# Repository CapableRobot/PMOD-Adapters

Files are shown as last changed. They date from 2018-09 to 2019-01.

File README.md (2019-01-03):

# PMOD Adapters

Designed by [Capable Robot Components](http://capablerobot.com).  Follow us on [Twitter](http://twitter.com/capablerobot) for product announcements and updates.

---

This repository contains schematics, layout, and bill of materials for various PMOD adapters and interfaces.  This currently includes:

* 2019-01-30 : [CRBFH0 - LED Debug](boards/LED-Debug)
* 2019-01-30 : [CR6QEG - PMOD Debug](boards/Debug)
* 2018-09-13 : [CR7CSZ - BeagleWire to PMOD](boards/BeagleWire) 
* 2018-09-13 : [CRRYEK - BeagleWire to Debug PMOD](boards/BeagleWire-Debug)

Additional designed will be added to this repository over time.  

| **Type** | **License** |
| --- | --- |
| Hardware | Copyright Capable Robot Components 2018 <br><br>This documentation describes Open Hardware and is licensed under the [CERN OHL v1.2 or later](https://www.ohwr.org/licenses/cern-ohl/license_versions/v1.2). <br/><br/> You may redistribute and modify this documentation under the terms of the CERN OHL v.1.2.  This documentation is distributed WITHOUT ANY EXPRESS OR IMPLIED WARRANTY, INCLUDING OF MERCHANTABILITY, SATISFACTORY QUALITY AND FITNESS FOR A PARTICULAR PURPOSE. Please see the CERN OHL v.1.2 for applicable conditions |
| Software | [MIT License](LICENSE.txt) |

More detailed information about the CERN License is available in the [license](license) folder and on the [CERN website](https://www.ohwr.org/projects/cernohl/wiki).

---

### [CRBFH0] LED Debug

| Top Render | Bottom Render |
| :---: | :---: |
| **Top Rendering** | **Bottom Rendering** |

This PCB allows a single PMOD to control 64 LEDs via a 4:16 address decoder and 4 mask control signals.  It was originally designed by H.Poetzl as part of the [Apertus project](https://www.apertus.org/pmod-debug).  Changes made to this version are:

- Changed 0402 resistors to 0603 packages.
- Changed the N channel MOSFETs from SC75 to SOT23 packages. 
- PCB layout changes to accommodate the larger components.

No schematic changes were made, meaning the PMOD interface is identical.

This board can be ordered at [OSH Park](https://oshpark.com/shared_projects/n7GHOesv) and costs $6.75 for a set of 3.



---

### [CR6QEG] PMOD Debug

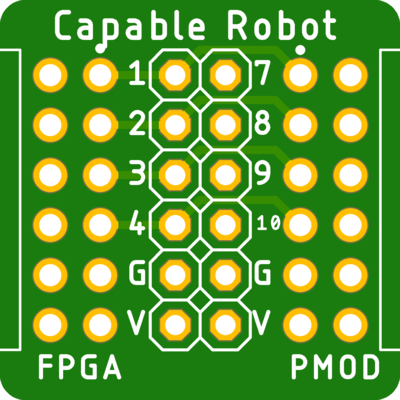
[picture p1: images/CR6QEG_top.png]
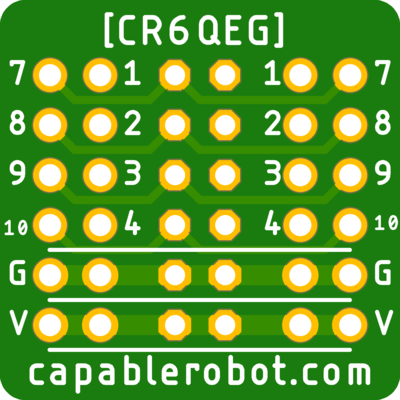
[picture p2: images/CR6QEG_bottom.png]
Bottom Render
|  |  |
| :---: | :---: |
| **Top Rendering** | **Bottom Rendering** |

This PCB adapts allows for probing of signals between an FPGA development board an a PMOD peripheral.  

A 2x6 right angle male header should be installed in the `FPGA` header and a 2x6 right angle female header should be installed into the `PMOD` header.

This board can be ordered at [OSH Park](https://oshpark.com/shared_projects/YEDBhzJa) and costs $3.20 for a set of 3.



---

### [CR7CSZ] BeagleWire to PMOD

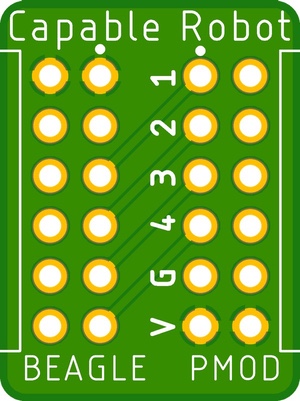
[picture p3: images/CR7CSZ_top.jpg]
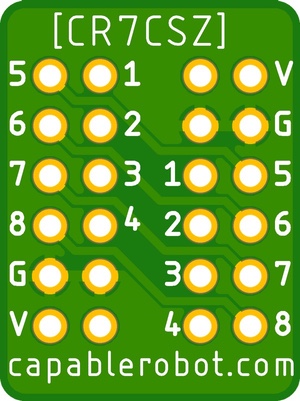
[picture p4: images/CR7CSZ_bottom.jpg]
Bottom Render
|  |  |
| :---: | :---: |
| **Top Rendering** | **Bottom Rendering** |

This PCB adapts standard PMOD peripherals to the BeagleWire PMOD connectors.  

The BeagleWire has a reversed pinout wherein the Power and Ground are on the right side of the connector (as you face a female PMOD on the BeagleWire) while all other PMOD hosts have the Power and Ground on the left side of the connector.

A 2x6 right angle male header should be installed in the `BEAGLE` header and a 2x6 right angle female header should be installed into the `PMOD` header.

This board can be ordered at [OSH Park](https://oshpark.com/shared_projects/sm0OcuML) and costs $2.40 for a set of 3.



---

### [CRRYEK] BeagleWire to Debug PMOD

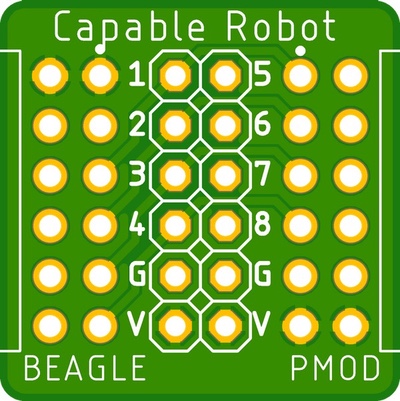
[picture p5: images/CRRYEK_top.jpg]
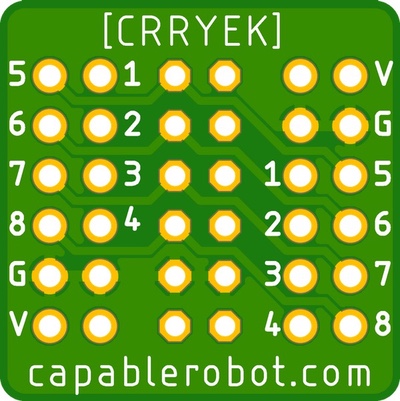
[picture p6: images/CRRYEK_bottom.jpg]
Bottom Render
|  |  |
| :---: | :---: |
| **Top Rendering** | **Bottom Rendering** |

This PCB adapts standard PMOD peripherals to the BeagleWire PMOD connectors.  It is similar to the CR7CSZ version but adds an additional 2x6 header (standard PMOD pinout) to aid in probing and debugging signals between the BeagleWire and the PMOD peripheral.

A 2x6 right angle male header should be installed in the `BEAGLE` header and a 2x6 right angle female header should be installed into the `PMOD` header.

This board can be ordered at [OSH Park](https://oshpark.com/shared_projects/SsbzeQ1o) and costs $3.20 for a set of 3.



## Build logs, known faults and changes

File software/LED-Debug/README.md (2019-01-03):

## LED Debug Migen Code

The `led-pmod.py` file here is a small driver for the LED Debug PMOD board.

| Top Render | Bottom Render |
| :---: | :---: |
| **Top Rendering** | **Bottom Rendering** |

This PCB allows a single PMOD to control 64 LEDs via a 4:16 address decoder and 4 mask control signals.  It was originally designed by H.Poetzl as part of the [Apertus project](https://www.apertus.org/pmod-debug) and they provide example [VHDL code](https://github.com/apertus-open-source-cinema/alpha-software/blob/master/axi3_hdmi/pmod_debug.vhd) showing how to address the LEDs.

Source files for this LED Debug PCB are available in this repository, see [https://github.com/CapableRobot/PMOD-Adapters](https://github.com/CapableRobot/PMOD-Adapters).

The python-based Migen code to address the LEDs is very simple

```python
class LedPmod(Module):
    def __init__(self, platform, value):
        
        clock = Signal()
        clock_strobe  = Signal()

        addr = Signal(4)
        mask = Signal(4)

        if platform == 'sim':
            div = 1
        else:
            div = 8

            for i in range(4):
                ledpmod_mask = platform.request("ledpmod_mask")
                ledpmod_addr = platform.request("ledpmod_addr")

                self.comb += ledpmod_mask.eq(mask.part(i,1))
                self.comb += ledpmod_addr.eq(addr.part(i,1))

        self.submodules.clk_div = ClockDiv(div, clock, clock_strobe)

        self.comb += mask.eq(Cat(
                        ~value.part(addr     ,1),
                        ~value.part(addr + 16,1),
                        ~value.part(addr + 32,1),
                        ~value.part(addr + 48,1)
                    ))

        self.sync += If(clock_strobe,
                            addr.eq(addr + 1),
                        )
```

This shows a few unique features to Migen (in comparison to Verilog or VHDL):

- The appropriate pins are requested from the passed-in platform object, instead of explicitly passed into the module.
- Signals are automatically initialized to 0, so no reset logic or signal is needed.
- Generated logic is easy to change at build time.  Here, the clock divider changes when the package is simulated.

Also included in the code here are two examples of using this 'driver'.

#### Chasing

```python
class LedPmodChaser(Module):
    
    def __init__(self, platform, maxperiod):
        NUM_LEDS = 64

        value = Signal(NUM_LEDS,reset=1)
        index = Signal(max=NUM_LEDS)

        counter = Signal(max=maxperiod+1)
        period = Signal(max=maxperiod+1)

        # Used to trigger the bit flip via the index.
        # without this signal, the active bit/LED will change
        # on every system clock (making it dimmer).
        strobe = Signal()

        self.submodules.leds = LedPmod(platform, value)
        
        self.comb += period.eq(maxperiod)
        self.sync += If(counter == 0,
                            index.eq(index + 1),
                            strobe.eq(1),
                            counter.eq(period),
                        ).Else(
                            counter.eq(counter - 1),
                        )

        for i in range(NUM_LEDS): 
            self.sync += If(index == i, If(strobe,
                            strobe.eq(0),
                            value[i].eq(~value[i]),
                        ))
```

This code starts at zero, every `maxperiod` ticks lights the next LED.  Once all leds are lit, every `maxperiod` ticks the LED which has been on the longest is turned off.

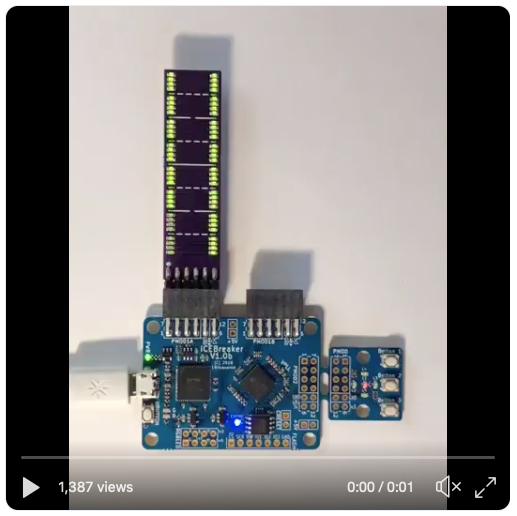
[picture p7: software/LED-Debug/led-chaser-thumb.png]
(https://twitter.com/osterwood/status/1080574349827026951)
|  |
| :-------------: |
| ICE Breaker running Chasing Demo  |

| Simulation of chasing |
| :-------------: |
| Simulation of chasing |

#### Counting

```python
class LedPmodCounter(Module):
    def __init__(self, platform, maxperiod):
        value = Signal(64)

        counter = Signal(max=maxperiod+1)
        period = Signal(max=maxperiod+1)

        self.submodules.leds = LedPmod(platform, value)
        
        self.comb += period.eq(maxperiod)
        self.sync += If(counter == 0,
                            value.eq(value + 1),
                            counter.eq(period),
                        ).Else(
                            counter.eq(counter - 1),
                        )
```

This code starts at zero, every `maxperiod` ticks increases the displayed value by 1.

| Simulation of counting |
| :-------------: |
| Simulation of counting |

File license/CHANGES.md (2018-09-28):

Here we are compiling a community changelog.

If you come up with a modification of our designs, please share it
with the community, log your changes below, and upload the files to
our GitHub repository.

# Change Format

**Your name**
*Date*
Description of modification

# Change Log

* **Chris Osterwood** *2018-09-13* Initial release of [CR7CSZ - BeagleWire to PMOD](boards/BeagleWire) and [CRRYEK - BeagleWire to Debug PMOD](boards/BeagleWire-Debug)

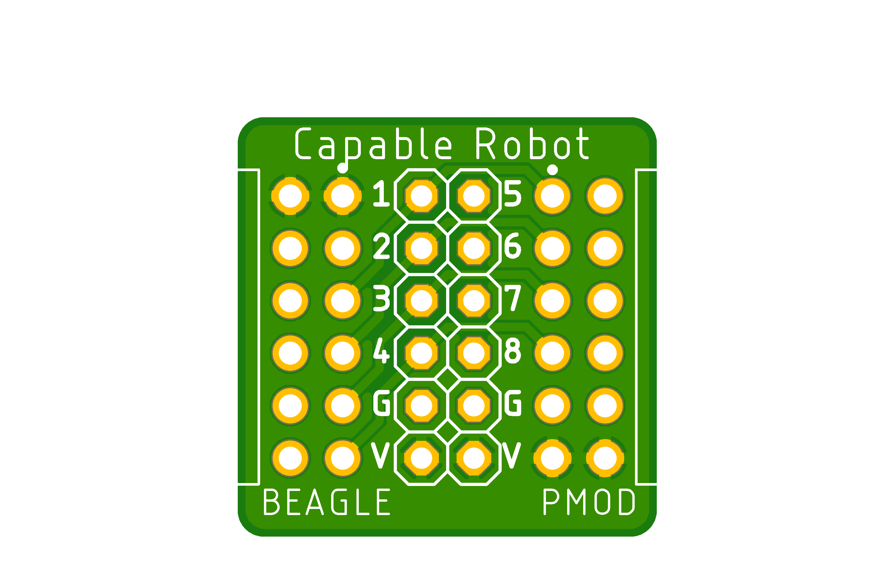
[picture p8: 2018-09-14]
boards/BeagleWire-Debug/top.png

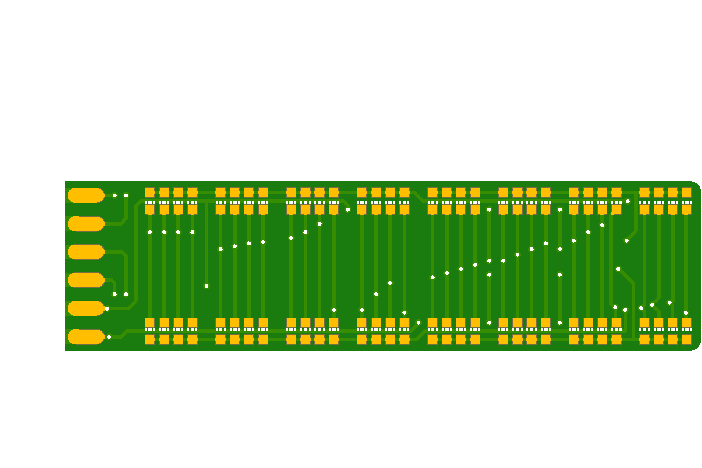
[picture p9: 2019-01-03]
boards/LED-Debug/top.png

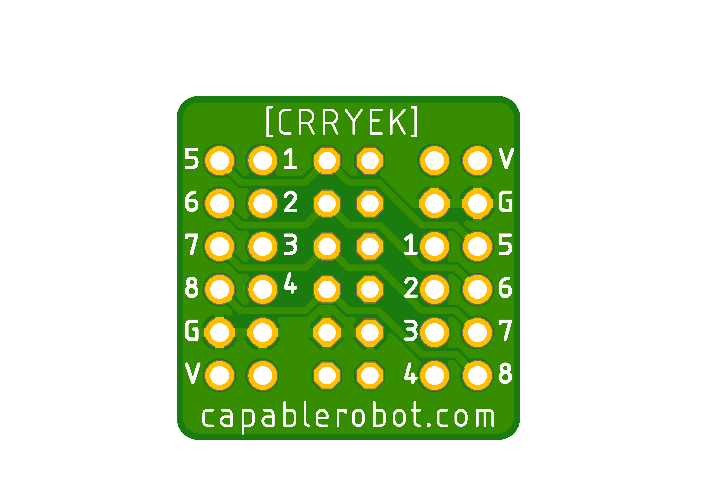
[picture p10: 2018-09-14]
boards/BeagleWire-Debug/bottom.png

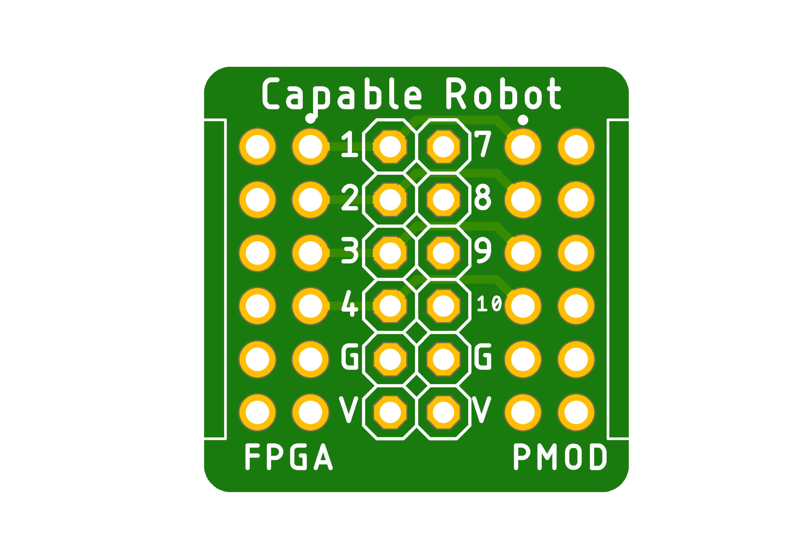
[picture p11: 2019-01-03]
boards/Debug/top.png

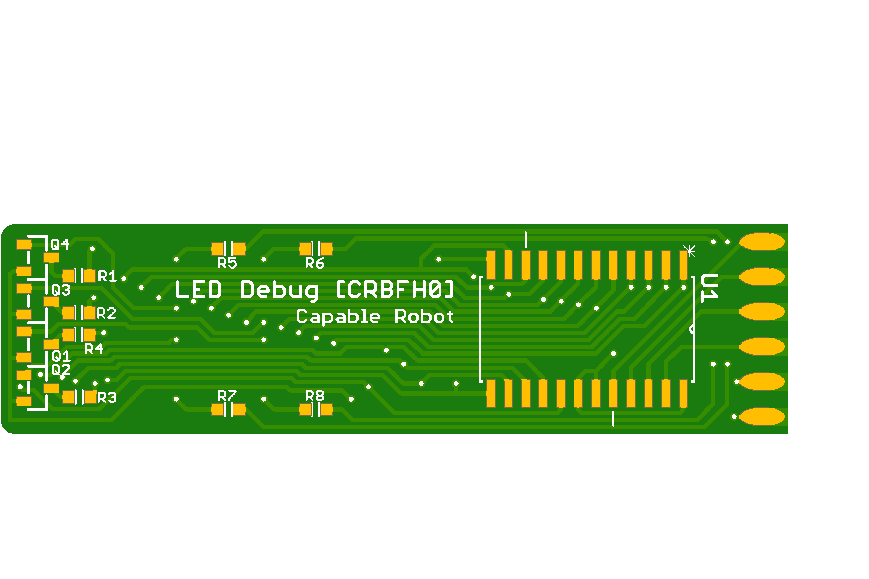
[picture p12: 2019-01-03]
boards/LED-Debug/bottom.png

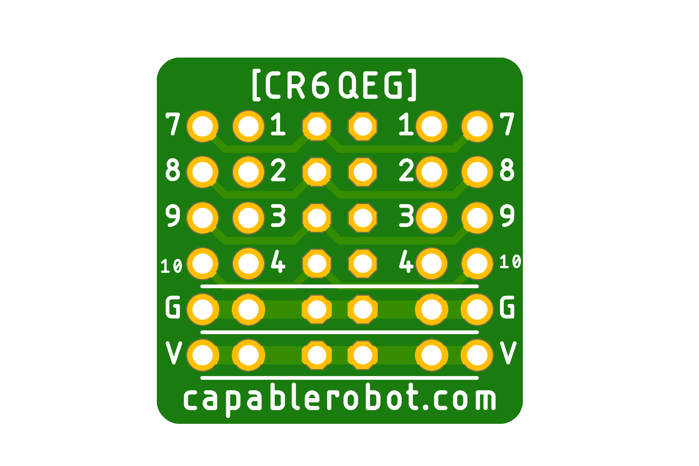
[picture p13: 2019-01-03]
boards/Debug/bottom.png

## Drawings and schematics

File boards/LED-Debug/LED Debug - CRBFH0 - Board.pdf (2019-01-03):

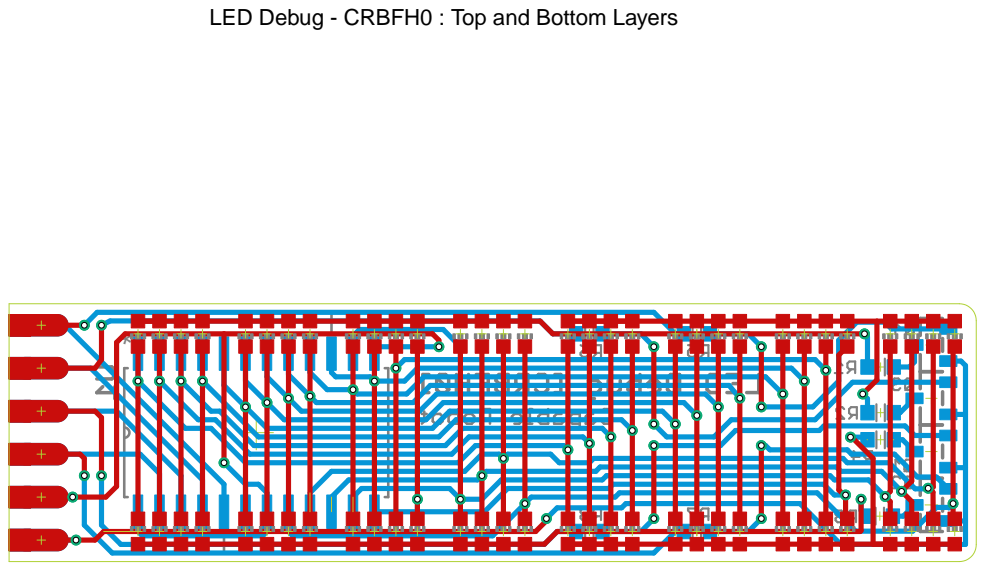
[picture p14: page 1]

LED Debug - CRBFH0 : Top and Bottom Layers

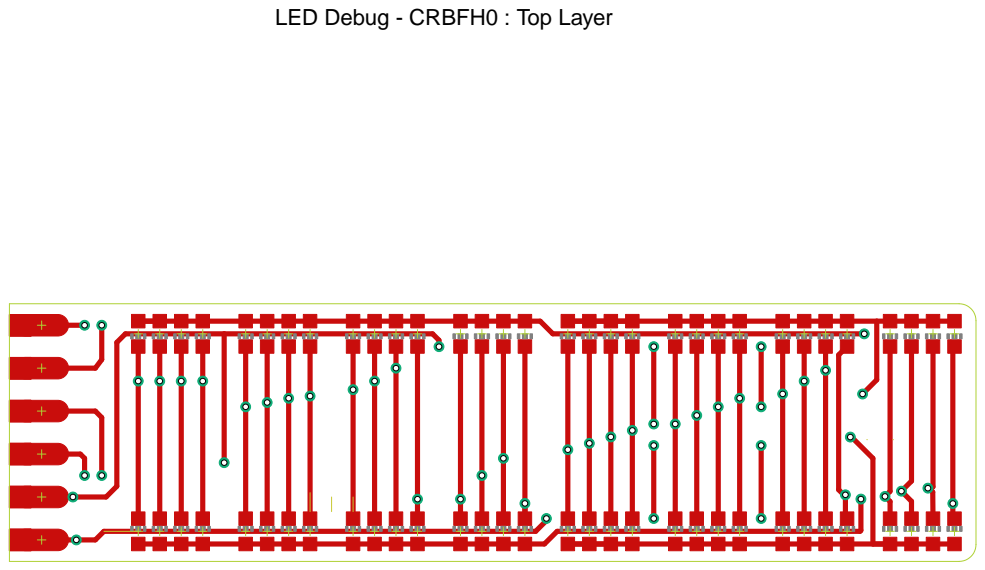
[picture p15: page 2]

LED Debug - CRBFH0 : Top Layer

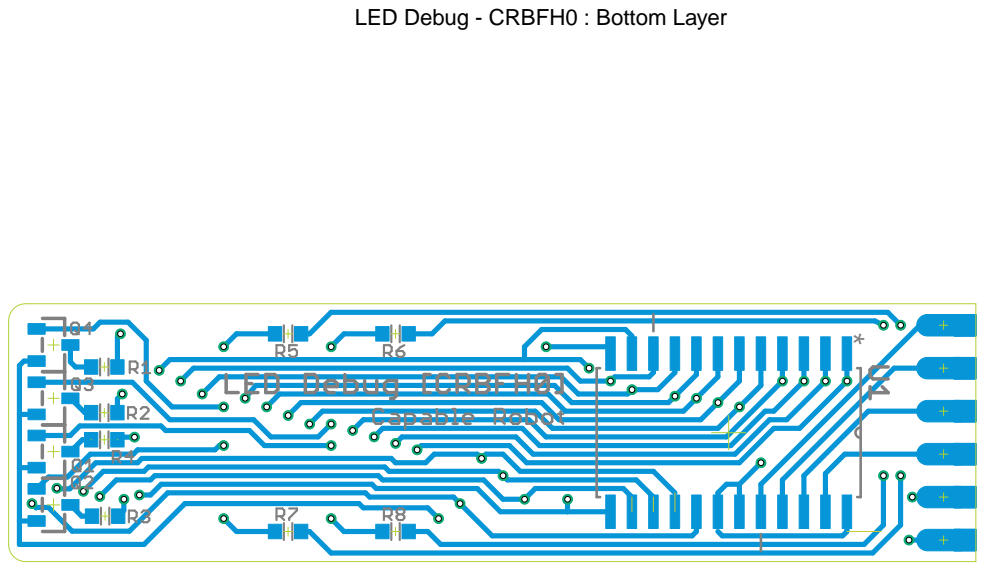
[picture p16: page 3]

LED Debug - CRBFH0 : Bottom Layer

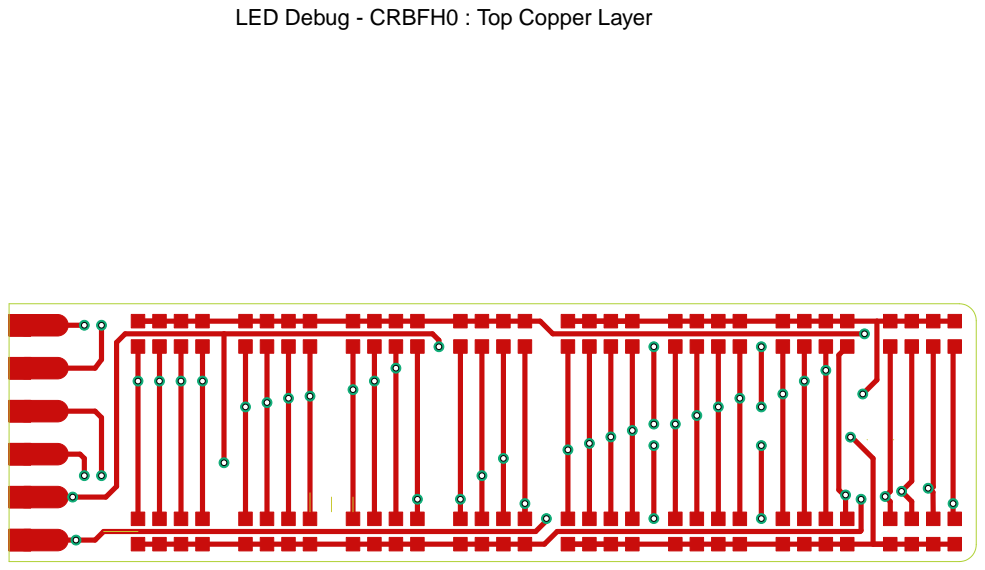
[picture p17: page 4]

LED Debug - CRBFH0 : Top Copper Layer

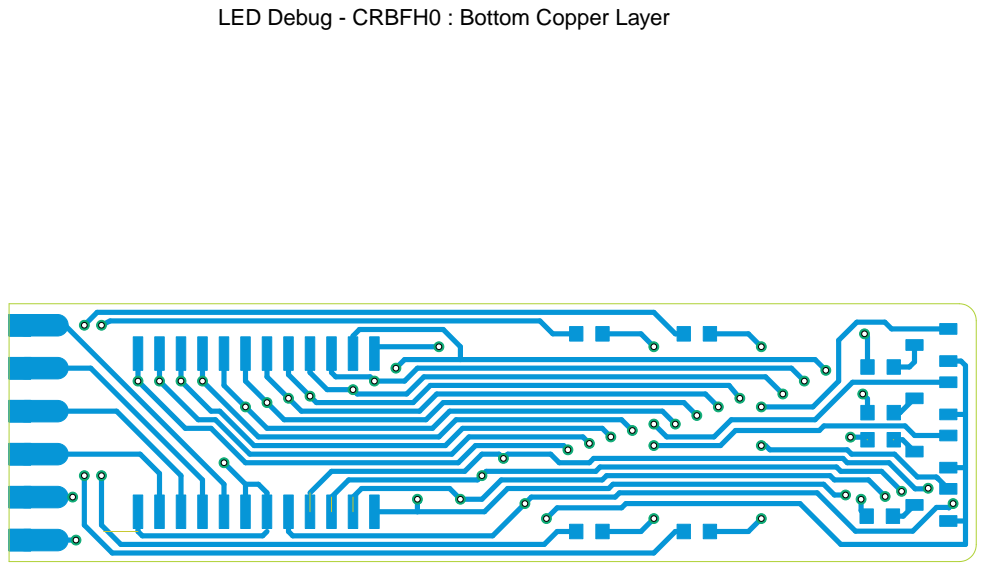
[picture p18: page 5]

LED Debug - CRBFH0 : Bottom Copper Layer

LED Debug - CRBFH0 : Top Paste Layer with Silkscreen

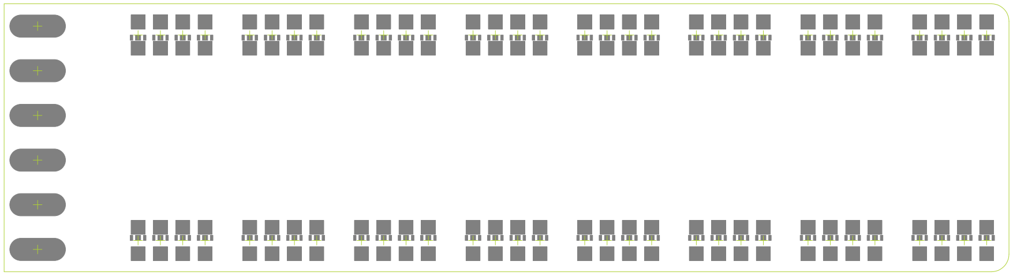
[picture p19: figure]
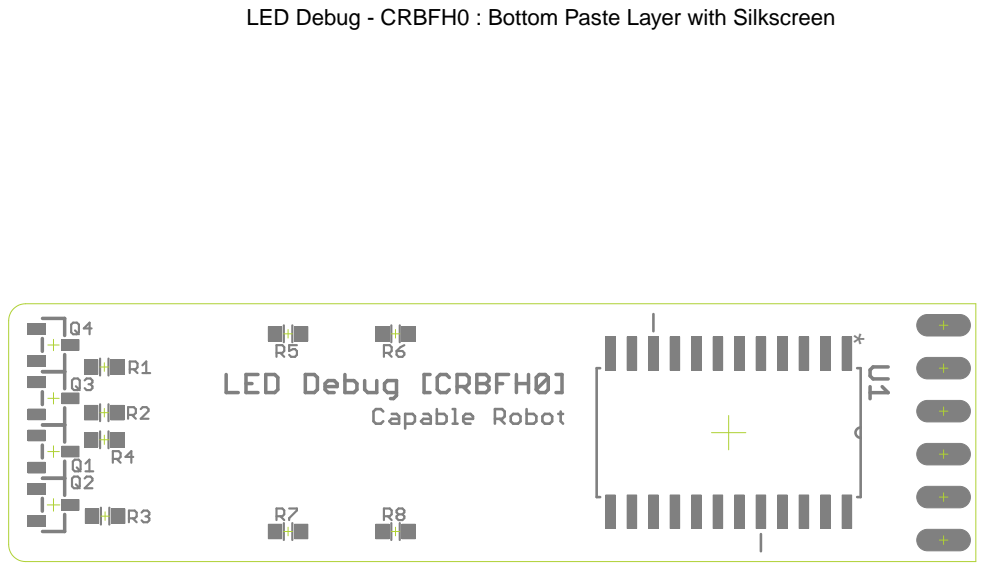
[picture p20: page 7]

LED Debug - CRBFH0 : Bottom Paste Layer with Silkscreen

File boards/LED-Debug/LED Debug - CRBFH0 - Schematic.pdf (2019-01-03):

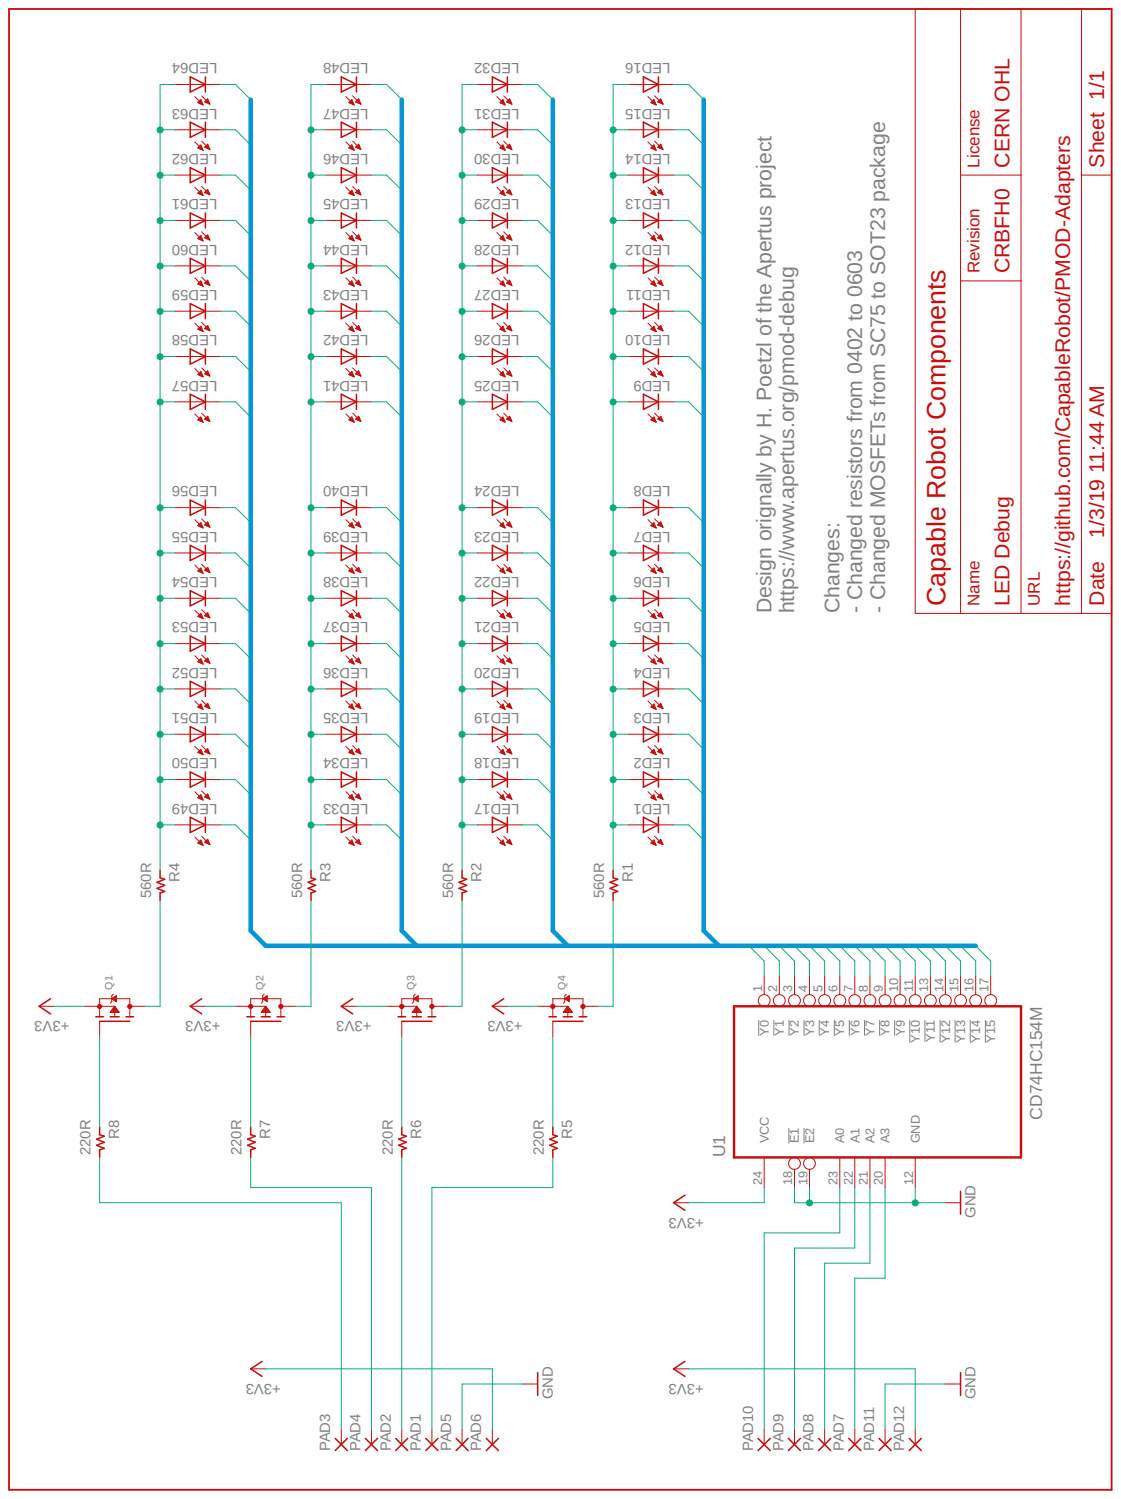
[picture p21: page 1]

Design orignally by H. Poetzl of the Apertus project https:/ w .apertus.org/pmod-debug Changes: - Changed resistors from 0402 to 0603

https:/ github.com/CapableRobot/PM

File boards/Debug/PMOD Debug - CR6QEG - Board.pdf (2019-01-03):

# Capable Robot

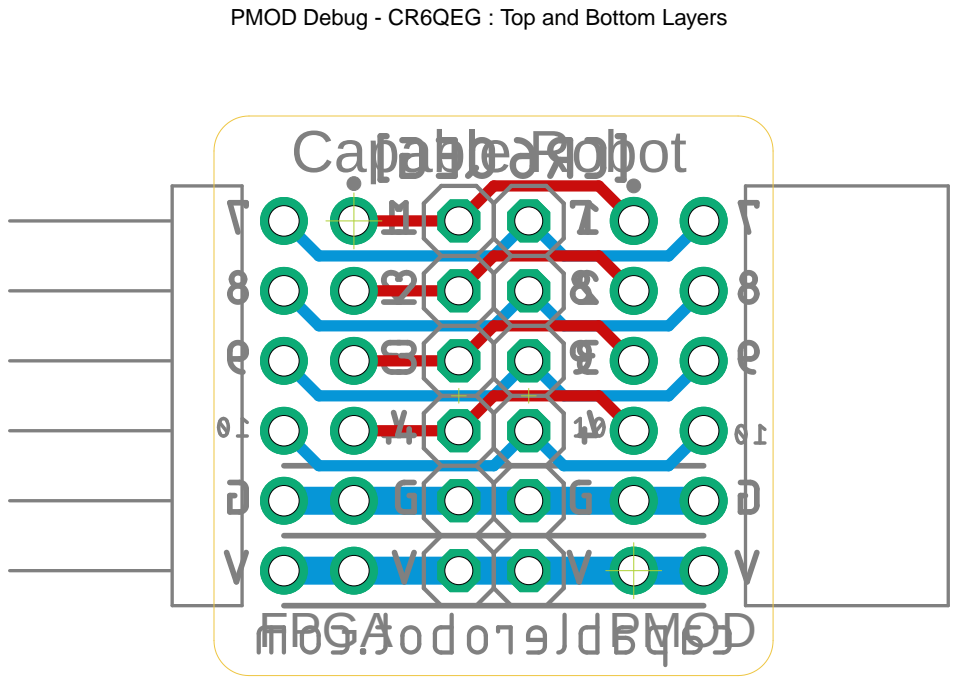
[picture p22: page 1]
FPGA; PMOD

PMOD Debug - CR6QEG : Top and Bottom Layers

# Capable Robot

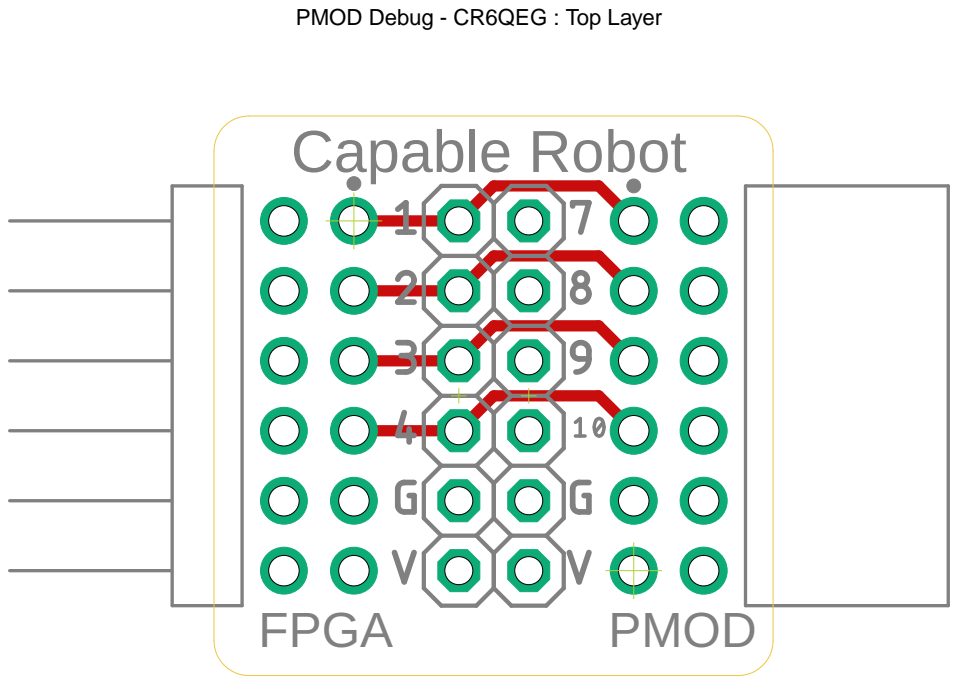
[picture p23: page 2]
FPGA; PMOD

PMOD Debug - CR6QEG : Top Layer

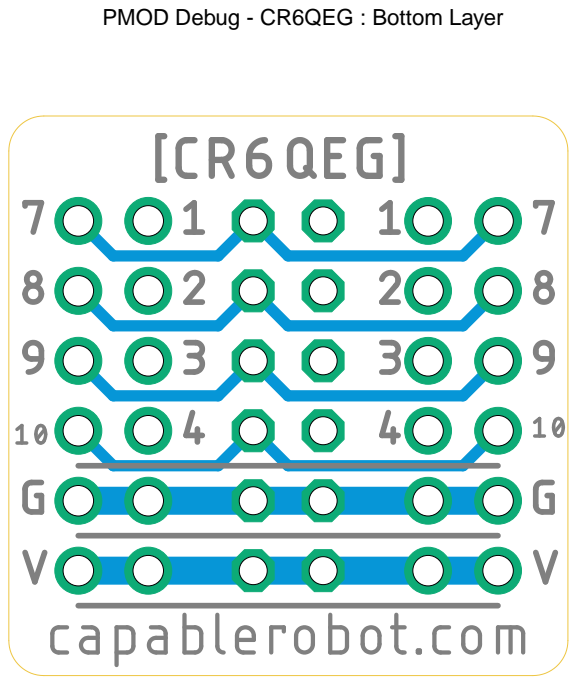
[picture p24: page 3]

PMOD Debug - CR6QEG : Bottom Layer

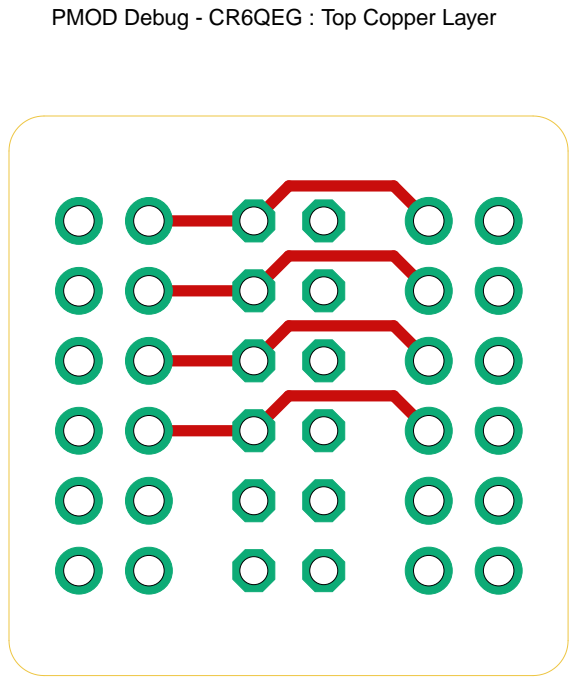
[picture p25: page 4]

PMOD Debug - CR6QEG : Top Copper Layer


PMOD Debug - CR6QEG : Bottom Copper Layer

# Capable Robot

FPGA; PMOD

PMOD Debug - CR6QEG : Top Paste Layer with Silkscreen


PMOD Debug - CR6QEG : Bottom Paste Layer with Silkscreen

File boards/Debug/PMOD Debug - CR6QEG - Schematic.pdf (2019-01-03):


PMOD PMOD GND GND GND GND GND PMOD FPGA GND IO1 1 IO2 2 IO3 3 IO4 4 GND 5 3V3 6 GND 11 3V3 12 IO8 10 IO7 9 IO6 8 IO5 7 +3V3 +3V3 +3V3 +3V3 123456 JP1 123456 JP2 +3V3 IO1 1 IO2 2 IO3 3 IO4 4 GND 5 3V3 6 GND 11 3V3 12 IO8 10 IO7 9 IO6 8 IO5 7 +3V3 IO4IO4 IO4 IO3IO3 IO3 IO2IO2 IO2 IO1IO1 IO1 IO7 IO7 IO7 IO8 IO8 IO8 IO9 IO9 IO9 IO10 IO10 IO10Date Sheet Revision Name Capable Robot Components URL License 1/3/19 10:28 AM 1/1 PMOD Debug CR6QEG https:/ github.com/CapableRobot/PMOD-Adapters CERN OHL v1.2

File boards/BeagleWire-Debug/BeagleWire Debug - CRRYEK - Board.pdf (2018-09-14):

# Ca]paKbEleYRRRobC[ot

BEAGLE; PMOD

PMOD to BeagleWire Debug - CRRYEK : Top and Bottom Layers

# Capable Robot

BEAGLE; PMOD

PMOD to BeagleWire Debug - CRRYEK : Top Layer

# [CRRYEK]


PMOD to BeagleWire Debug - CRRYEK : Bottom Layer


PMOD to BeagleWire Debug - CRRYEK : Top Copper Layer


PMOD to BeagleWire Debug - CRRYEK : Bottom Copper Layer

# Capable Robot

BEAGLE; PMOD

PMOD to BeagleWire Debug - CRRYEK : Top Paste Layer with Silkscreen

# [CRRYEK]


PMOD to BeagleWire Debug - CRRYEK : Bottom Paste Layer with Silkscreen

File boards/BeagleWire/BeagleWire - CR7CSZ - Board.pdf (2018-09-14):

# Ca]paZbSleC7RRoCb[ot

BEAGLE; PMOD

PMOD to BeagleWire - CR7CSZ : Top and Bottom Layers

# Capable Robot

BEAGLE PMOD

PMOD to BeagleWire - CR7CSZ : Top Layer

# [CR7CSZ]


PMOD to BeagleWire - CR7CSZ : Bottom Layer


PMOD to BeagleWire - CR7CSZ : Top Copper Layer


PMOD to BeagleWire - CR7CSZ : Bottom Copper Layer

PMOD to BeagleWire - CR7CSZ : Top Paste Layer with Silkscreen

Capable Robot; BEAGLE PMOD

# [CR7CSZ]


PMOD to BeagleWire - CR7CSZ : Bottom Paste Layer with Silkscreen

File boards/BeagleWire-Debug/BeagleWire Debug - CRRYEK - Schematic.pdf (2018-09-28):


URL
https://github.com/CapableRobot/PMOD-Adapters

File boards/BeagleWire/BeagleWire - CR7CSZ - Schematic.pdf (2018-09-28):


URL
https://github.com/CapableRobot/PMOD-Adapters

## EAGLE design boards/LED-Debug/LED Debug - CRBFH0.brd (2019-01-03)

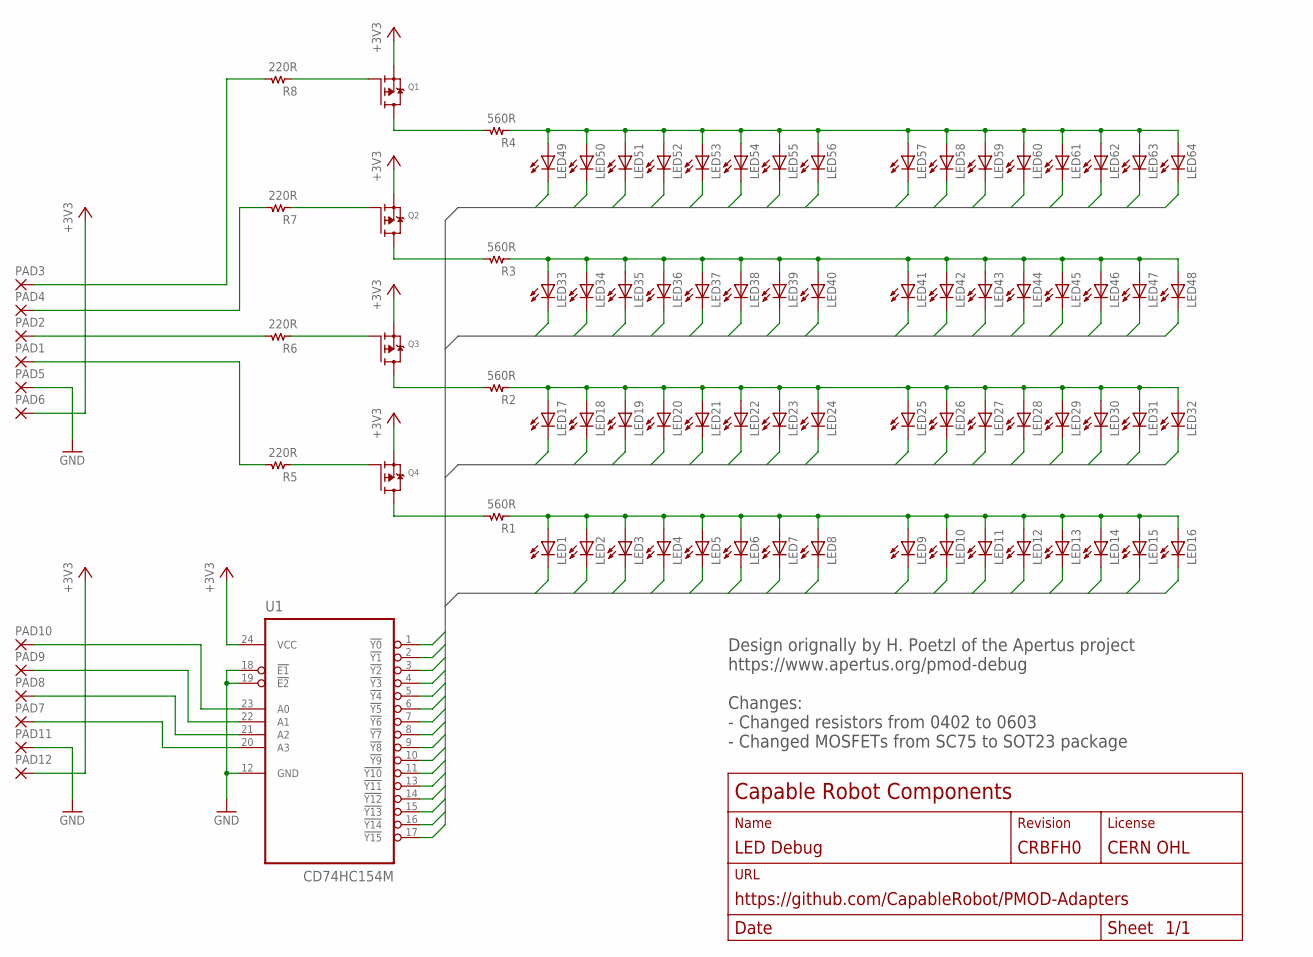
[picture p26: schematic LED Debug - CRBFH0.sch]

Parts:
LED1, LED2, LED3, LED4, LED5, LED6, LED7, LED8, LED9, LED10, LED11, LED12, LED13, LED14, LED15, LED16, LED17, LED18, LED19, LED20, LED21, LED22, LED23, LED24, LED25, LED26, LED27, LED28, LED29, LED30, LED31, LED32, LED33, LED34, LED35, LED36, LED37, LED38, LED39, LED40, LED41, LED42, LED43, LED44, LED45, LED46, LED47, LED48, LED49, LED50, LED51, LED52, LED53, LED54, LED55, LED56, LED57, LED58, LED59, LED60, LED61, LED62, LED63, LED64: LEDCHIP-LED0603; CHIP-LED0603
PAD1, PAD2, PAD3, PAD4, PAD5, PAD6, PAD7, PAD8, PAD9, PAD10, PAD11, PAD12: SMD2HR; SMD1.27-3.175HR
Q1, Q2, Q3, Q4: MOSFET-P; SOT23-R
R1, R2, R3, R4: 560R; 0603
R5, R6, R7, R8: 220R; 0603
U1: CD74HC154M; SOIC127P1030X265-24N

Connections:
+3V3: PAD6.1, PAD12.1, Q1.2 (S), Q2.2 (S), Q3.2 (S), Q4.2 (S), U1.24 (VCC)
C0: LED1.C, LED17.C, LED33.C, LED49.C, U1.1 (!Y0)
C1: LED2.C, LED18.C, LED34.C, LED50.C, U1.2 (!Y1)
C2: LED3.C, LED19.C, LED35.C, LED51.C, U1.3 (!Y2)
C3: LED4.C, LED20.C, LED36.C, LED52.C, U1.4 (!Y3)
C4: LED5.C, LED21.C, LED37.C, LED53.C, U1.5 (!Y4)
C5: LED6.C, LED22.C, LED38.C, LED54.C, U1.6 (!Y5)
C6: LED7.C, LED23.C, LED39.C, LED55.C, U1.7 (!Y6)
C7: LED8.C, LED24.C, LED40.C, LED56.C, U1.8 (!Y7)
C8: LED9.C, LED25.C, LED41.C, LED57.C, U1.9 (!Y8)
C9: LED10.C, LED26.C, LED42.C, LED58.C, U1.10 (!Y9)
C10: LED11.C, LED27.C, LED43.C, LED59.C, U1.11 (!Y10)
C11: LED12.C, LED28.C, LED44.C, LED60.C, U1.13 (!Y11)
C12: LED13.C, LED29.C, LED45.C, LED61.C, U1.14 (!Y12)
C13: LED14.C, LED30.C, LED46.C, LED62.C, U1.15 (!Y13)
C14: LED15.C, LED31.C, LED47.C, LED63.C, U1.16 (!Y14)
C15: LED16.C, LED32.C, LED48.C, LED64.C, U1.17 (!Y15)
GND: PAD5.1, PAD11.1, U1.12 (GND), U1.18 (!E1), U1.19 (!E2)
unnamed: LED1.A, LED2.A, LED3.A, LED4.A, LED5.A, LED6.A, LED7.A, LED8.A, LED9.A, LED10.A, LED11.A, LED12.A, LED13.A, LED14.A, LED15.A, LED16.A, R1.1
unnamed: LED17.A, LED18.A, LED19.A, LED20.A, LED21.A, LED22.A, LED23.A, LED24.A, LED25.A, LED26.A, LED27.A, LED28.A, LED29.A, LED30.A, LED31.A, LED32.A, R2.1
unnamed: LED33.A, LED34.A, LED35.A, LED36.A, LED37.A, LED38.A, LED39.A, LED40.A, LED41.A, LED42.A, LED43.A, LED44.A, LED45.A, LED46.A, LED47.A, LED48.A, R3.1
unnamed: LED49.A, LED50.A, LED51.A, LED52.A, LED53.A, LED54.A, LED55.A, LED56.A, LED57.A, LED58.A, LED59.A, LED60.A, LED61.A, LED62.A, LED63.A, LED64.A, R4.1
unnamed: Q1.3 (D), R4.2
unnamed: Q2.3 (D), R3.2
unnamed: Q4.3 (D), R1.2
unnamed: Q3.3 (D), R2.2
unnamed: Q1.1 (G), R8.1
unnamed: Q2.1 (G), R7.1
unnamed: Q4.1 (G), R5.1
unnamed: Q3.1 (G), R6.1
unnamed: PAD10.1, U1.23 (A0)
unnamed: PAD9.1, U1.22 (A1)
unnamed: PAD8.1, U1.21 (A2)
unnamed: PAD7.1, U1.20 (A3)
unnamed: PAD1.1, R5.2
unnamed: PAD2.1, R6.2
unnamed: PAD3.1, R8.2
unnamed: PAD4.1, R7.2

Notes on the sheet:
Design orignally by H. Poetzl of the Apertus project https://www.apertus.org/pmod-debug Changes: - Changed resistors from 0402 to 0603 - Changed MOSFETs from SC75 to SOT23 package

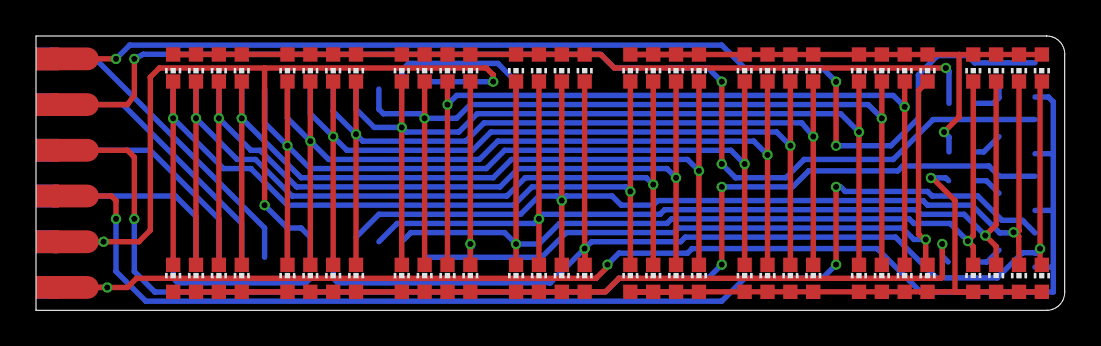
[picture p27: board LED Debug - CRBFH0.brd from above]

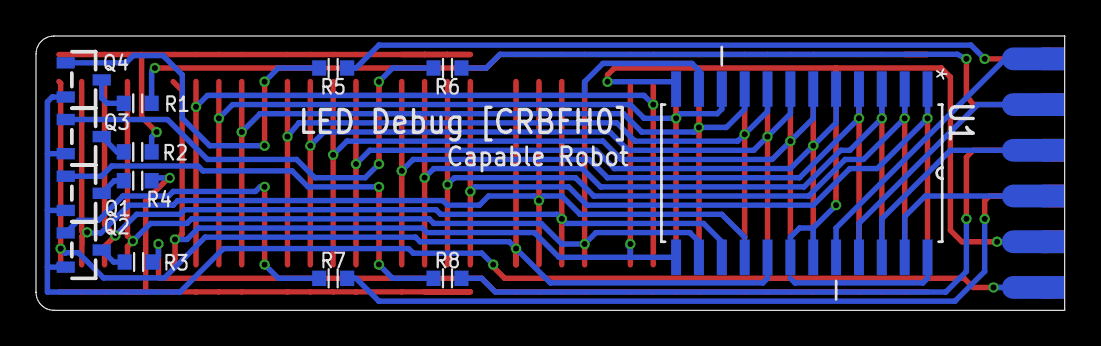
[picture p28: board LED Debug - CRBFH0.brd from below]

Board: 2 copper layers, 57.1 x 15.2 mm, 89 parts (19 on the bottom side), 38 nets.

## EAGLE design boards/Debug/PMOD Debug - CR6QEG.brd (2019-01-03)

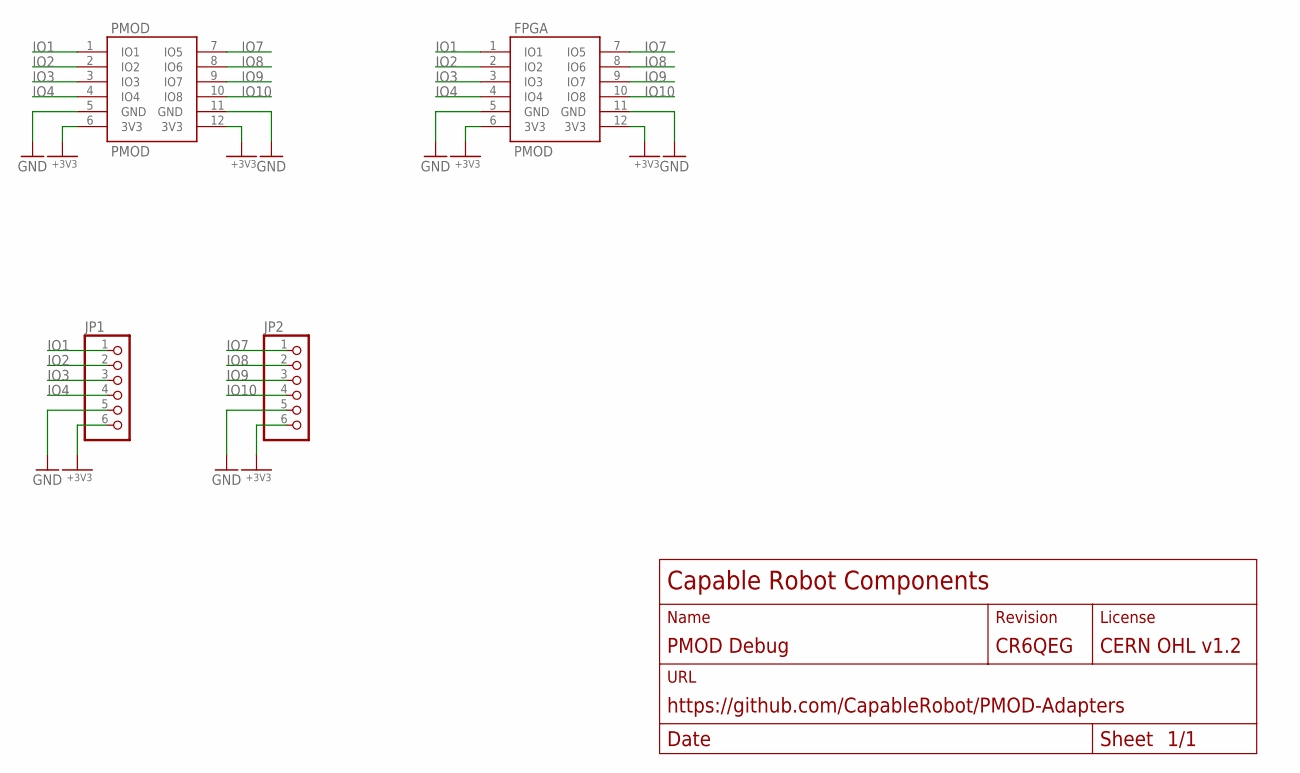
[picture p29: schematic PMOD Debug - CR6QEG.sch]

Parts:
FPGA: PMOD-PERIPH; HDRRA12W64P254_2X6_1524X254X556B
JP1, JP2: PINHD-1X6; 1X06
PMOD: PMOD-HOST; HDRRAR12W64P254_2X6_1524X736X556B

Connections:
+3V3: FPGA.6 (3V3), FPGA.12 (3V3), JP1.6, JP2.6, PMOD.6 (3V3), PMOD.12 (3V3)
GND: FPGA.5 (GND), FPGA.11 (GND), JP1.5, JP2.5, PMOD.5 (GND), PMOD.11 (GND)
IO1: FPGA.1 (IO1), JP1.1, PMOD.1 (IO1)
IO2: FPGA.2 (IO2), JP1.2, PMOD.2 (IO2)
IO3: FPGA.3 (IO3), JP1.3, PMOD.3 (IO3)
IO4: FPGA.4 (IO4), JP1.4, PMOD.4 (IO4)
IO7: FPGA.7 (IO5), JP2.1, PMOD.7 (IO5)
IO8: FPGA.8 (IO6), JP2.2, PMOD.8 (IO6)
IO9: FPGA.9 (IO7), JP2.3, PMOD.9 (IO7)
IO10: FPGA.10 (IO8), JP2.4, PMOD.10 (IO8)

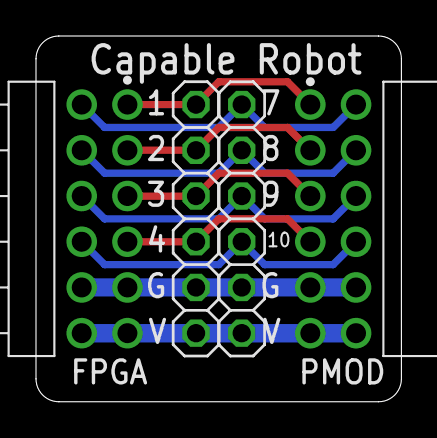
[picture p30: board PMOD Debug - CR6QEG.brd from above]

Board: 2 copper layers, 20.3 x 20.3 mm, 4 parts (0 on the bottom side), 10 nets.

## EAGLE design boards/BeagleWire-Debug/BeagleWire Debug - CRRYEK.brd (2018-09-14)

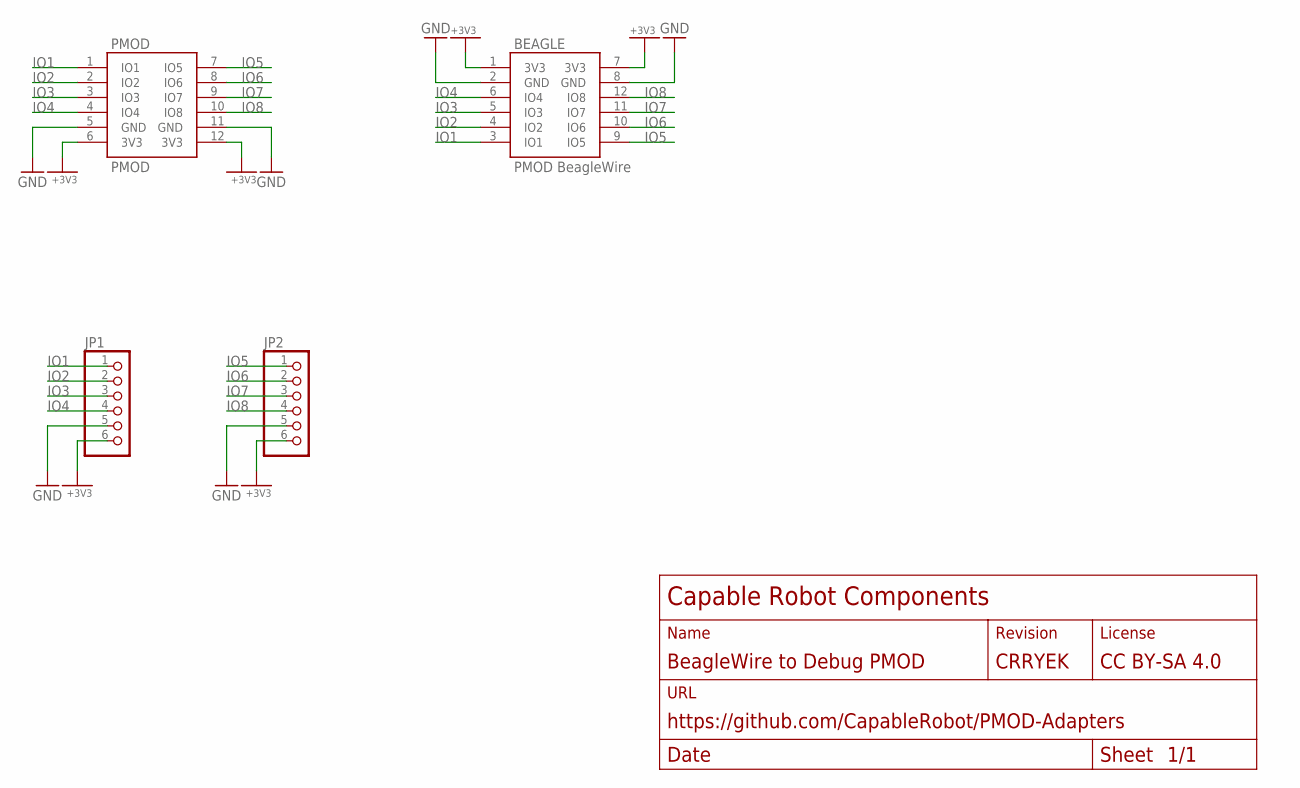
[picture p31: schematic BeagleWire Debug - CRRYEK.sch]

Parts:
BEAGLE: PMOD-BEAGLEWIRE; HDRRA12W64P254_2X6_1524X254X556B
JP1, JP2: PINHD-1X6; 1X06
PMOD: PMOD-HOST; HDRRAR12W64P254_2X6_1524X736X556B

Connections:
+3V3: BEAGLE.1 (3V3), BEAGLE.7 (3V3), JP1.6, JP2.6, PMOD.6 (3V3), PMOD.12 (3V3)
GND: BEAGLE.2 (GND), BEAGLE.8 (GND), JP1.5, JP2.5, PMOD.5 (GND), PMOD.11 (GND)
IO1: BEAGLE.3 (IO1), JP1.1, PMOD.1 (IO1)
IO2: BEAGLE.4 (IO2), JP1.2, PMOD.2 (IO2)
IO3: BEAGLE.5 (IO3), JP1.3, PMOD.3 (IO3)
IO4: BEAGLE.6 (IO4), JP1.4, PMOD.4 (IO4)
IO5: BEAGLE.9 (IO5), JP2.1, PMOD.7 (IO5)
IO6: BEAGLE.10 (IO6), JP2.2, PMOD.8 (IO6)
IO7: BEAGLE.11 (IO7), JP2.3, PMOD.9 (IO7)
IO8: BEAGLE.12 (IO8), JP2.4, PMOD.10 (IO8)

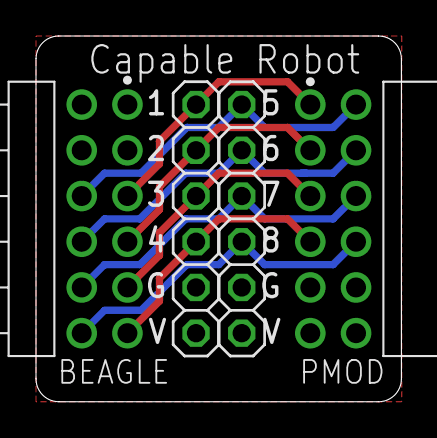
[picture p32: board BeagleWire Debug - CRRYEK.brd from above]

Board: 2 copper layers, 20.3 x 20.3 mm, 4 parts (0 on the bottom side), 10 nets.

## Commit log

2018-09-14 Adding PMOD to BeagleWire PMOD adapter
    [PMOD to BeagleWire - CR7CSZ.brd, PMOD to BeagleWire - CR7CSZ.sch]
2018-09-14 Adding PMOD to BeagleWire PMOD (with debug header) adapter
    [PMOD to BeagleWire Debug - CRRYEK.brd, PMOD to BeagleWire Debug - CRRYEK.sch]
2018-09-14 Change file and folder names
    [BeagleWire - CR7CSZ.brd, BeagleWire - CR7CSZ.sch, BeagleWire Debug - CRRYEK.brd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]
2018-09-28 Change license from CC BY-SA to CERN OHL
    [BeagleWire - CR7CSZ.sch, BeagleWire Debug - CRRYEK.sch]
2019-01-03 Adding standard PMOD debug
    [PMOD Debug - CR6QEG.brd, PMOD Debug - CR6QEG.sch]
2019-01-03 Change font
    [PMOD Debug - CR6QEG.brd]
2019-01-03 Resize board images
2019-01-03 Added text about standard PMOD debug board
2019-01-03 Added LED debug board, modified from Apertus project LED debug board
    [LED Debug - CRBFH0.brd, LED Debug - CRBFH0.sch]
2019-01-03 Update readme with info and links to LED Debug PCB
2019-01-03 Added migen software for LED Debug PMOD

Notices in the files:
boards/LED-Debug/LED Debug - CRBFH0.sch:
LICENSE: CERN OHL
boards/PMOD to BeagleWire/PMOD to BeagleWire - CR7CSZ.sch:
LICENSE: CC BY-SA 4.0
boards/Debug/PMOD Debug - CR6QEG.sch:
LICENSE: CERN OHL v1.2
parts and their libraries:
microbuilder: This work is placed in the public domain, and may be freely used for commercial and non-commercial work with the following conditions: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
